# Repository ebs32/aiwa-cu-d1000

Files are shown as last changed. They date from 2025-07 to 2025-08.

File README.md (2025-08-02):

# AIWA CU-D1000 HiFi

A repository where I track all the work I do for servicing my AIWA CU-D1000 HiFi System.

**Note** When opening schematics in OrCAD Capture, you may need to update the library paths, as Capture stores absolute paths for libraries, which can cause issues when the project is moved or cloned.

## MX-D10 Amplifier

### Audio Power Amplifier Replacement

Due to audio performance issues, I tested the amplifier by injecting a signal and monitoring the output. While increasing the volume, one of the channels failed. Upon further inspection, I found that the installed audio power amplifier IC, the **STK4204MK2**, is rated for a maximum supply voltage of **55 VDC**, whereas the measured rail voltage was approximately **56 VDC**, slightly exceeding the recommended limit.

It is likely that the unregulated power supply caused the rail voltage to rise from the nominal **51 VDC** (as specified in the service manual) to approximately **56 VDC** when the mains input increased from **220 VAC** to **230 VAC**, around 2003. However, this particular unit was not in use at that time. I also observed that increasing the volume causes the supply rail to step up from **25 VDC** to **51 VDC**.

With the original IC damaged, a replacement was necessary; however, sourcing one proved challenging, as most of these devices are only available through aftermarket channels. I identified a reseller claiming to offer a genuine **STK4204MK5**, a compatible model featuring lower total harmonic distortion (THD) and a higher maximum supply voltage rating of **57 VDC**.

Since I had to remove the heatsink to install the new IC, I took the opportunity to replace the old thermal paste with thermal pads to improve heat transfer from all regulators mounted to the heatsink, as well as from the new audio power amplifier IC.

### Audio Power Amplifier Filter Capacitor Replacement

When I opened the MX-D10 amplifier, I found that the filter capacitors for the audio power amplifier were swollen:

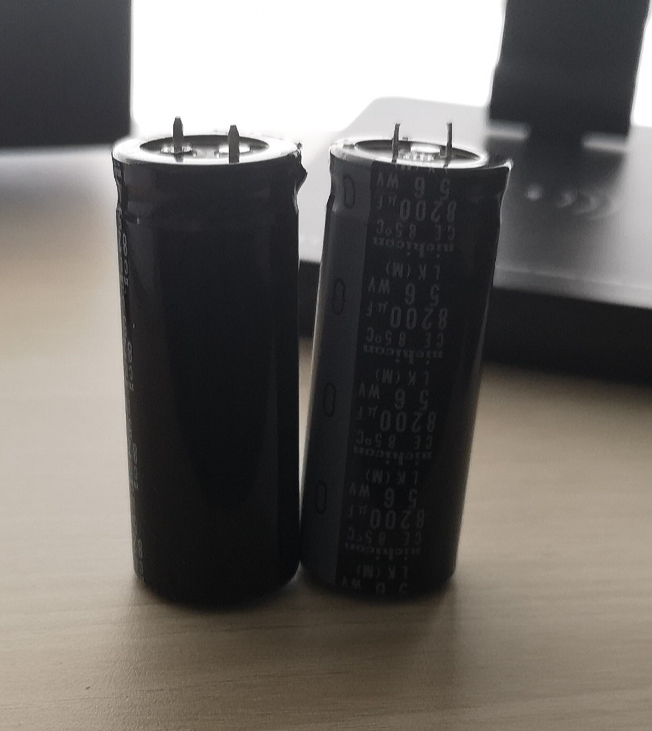
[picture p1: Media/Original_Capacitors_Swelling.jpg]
Original_Capacitors_Swelling


Since I could not find capacitors that fit in the available space on the main PCB, I had to come up with an alternative. Based on the options available from authorized resellers, I designed a simple PCB to mount the new capacitors:

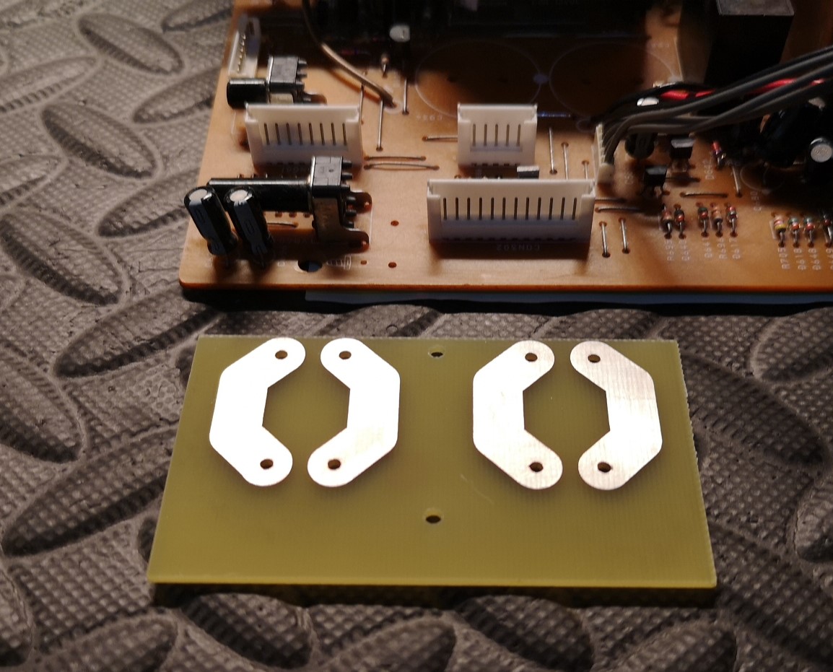
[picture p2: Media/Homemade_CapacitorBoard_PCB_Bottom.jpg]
Homemade_CapacitorBoard_PCB_Bottom


I also designed a mechanical support to mount the PCB. It attaches to the heatsink of the bridge rectifier, which is located behind the capacitors being replaced:

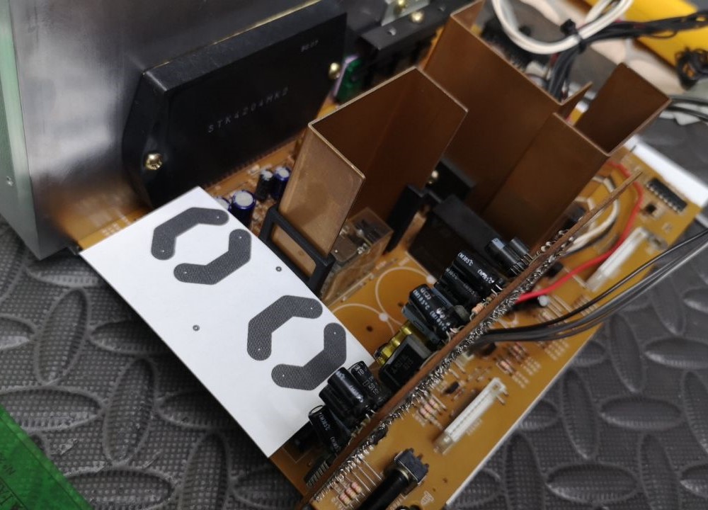
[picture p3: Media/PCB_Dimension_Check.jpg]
PCB_Dimension_Check


The PCB is connected to the main board using manually twisted wires:

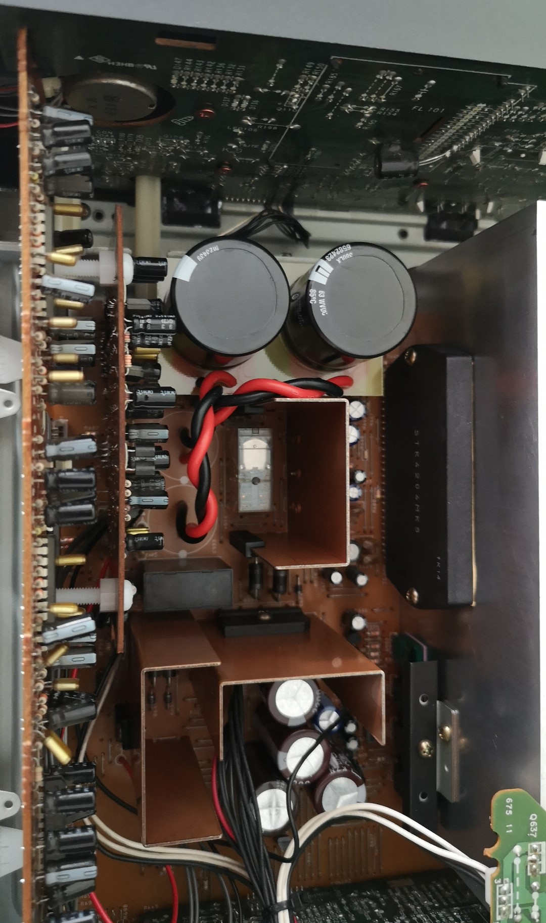
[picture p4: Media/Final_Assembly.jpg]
Final_Assembly


The PCB design is available in the [CapacitorBoard](Boards/CapacitorBoard/) directory, and the mechanical support design can be found in the [Designs](Designs/) directory.

### Filter Capacitor Replacement

Although the installed filter capacitors appeared to meet specifications, I opted to replace all of them.

## FX-W10 Cassette Deck

There was noticeable noise coming from the capstan motor of each deck, so I carefully disassembled them, cleaned all components, and lubricated the bearings. The noise is now nearly imperceptible.

## TX-D10 Tuner

The clock suffers from clock drift. I thought the ceramic crystal oscillator was the cause, so I replaced it. However, the drift still persists. I suppose I forgot those times when clocks needed periodic manual adjustments, so I’m not concerned about it.

## DX-D10 CD Player

I identified a couple of issues with the CD player.

One of them is read errors when playing slightly scratched discs. Although I purchased a CD optical pickup unit advertised as NOS (New Old Stock) to replace the existing one, I decided not to proceed, as the original unit still reads most discs without errors. Additionally, performance can be improved by fine-tuning the focus bias, tracking gain, and tracking balance.

The other issue was that the CD tray would close immediately after opening, preventing a disc from being placed on it. I fixed the issue by cleaning the switch that detects whether the tray is open or closed.

## References

The service manual for the amplifier, the cassette deck, the tuner and the graphic equalizer is available [here](Docs/CU-D1000_ServiceManual.pdf). I could not find the service manual for the CD player or the turntable.

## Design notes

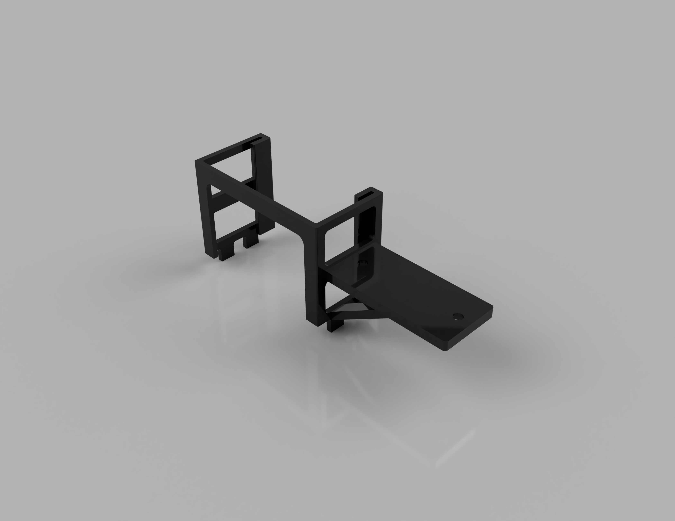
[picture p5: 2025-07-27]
Media/CapacitorBoard_Support_Render.png

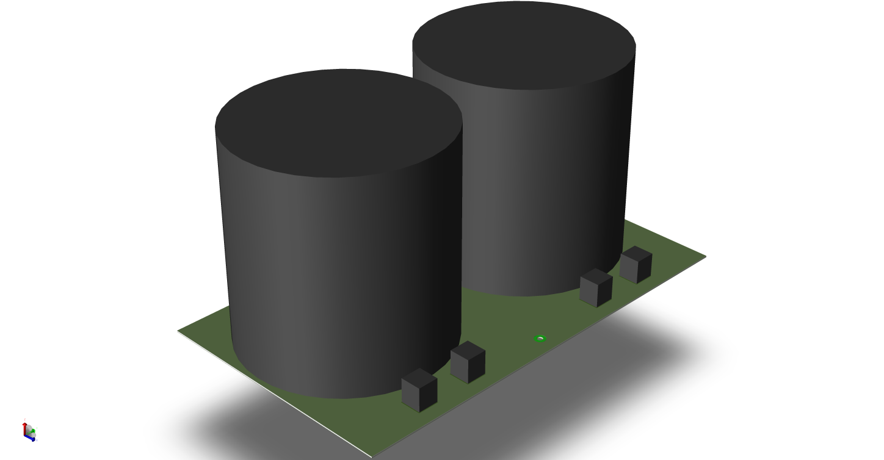
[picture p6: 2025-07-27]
Media/CapacitorBoard_3D_View_Top.png

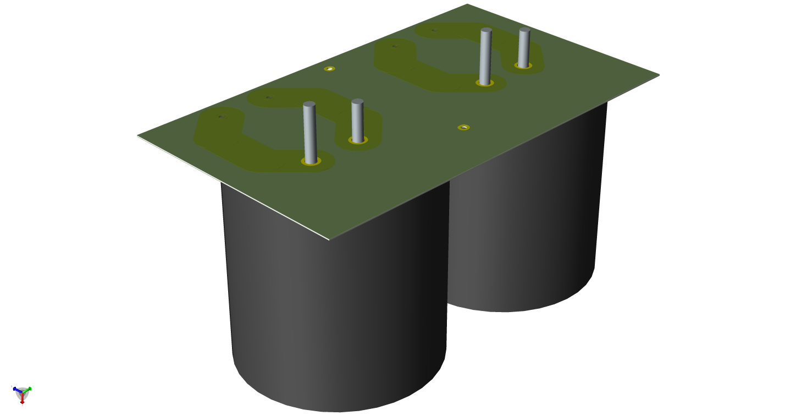
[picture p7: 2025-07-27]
Media/CapacitorBoard_3D_View_Bottom.png

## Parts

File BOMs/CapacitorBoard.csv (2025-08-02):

Reference | Part Number
C1 | 380LX822M063A032
C2 | 380LX822M063A032

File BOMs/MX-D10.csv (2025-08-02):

Reference | Part Number
C676 | ELXZ250ELL471MJ16S
C677 | EKZN250ELL682MMP1S
C678 | UPM1J102MHD6AA
C931 | EKY-350ELL332MMP1S
C932 | EKY-350ELL332MMP1S
MISC | PL-05-5-1016
MISC | 4051100100017

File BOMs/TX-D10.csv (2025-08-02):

Reference | Part Number
CR1 | CSTLS4M19G56-A0
CR1 | CSTLS4M19G53-A0

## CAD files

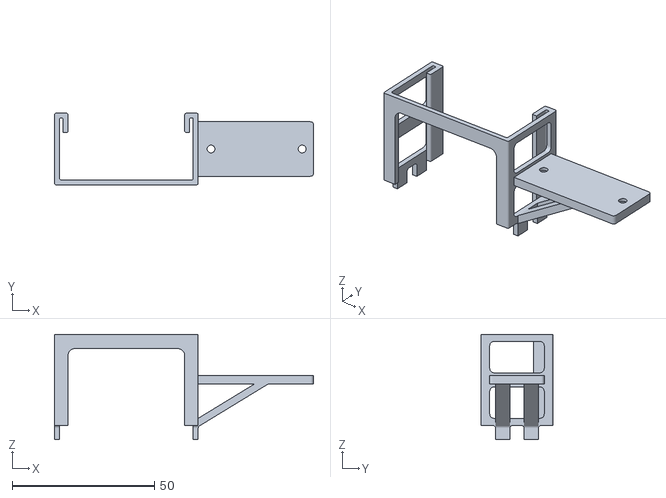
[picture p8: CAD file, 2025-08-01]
Manufacturing/Mechanical/CapacitorBoard_Support.stl
91.0 x 25.1 x 37.0

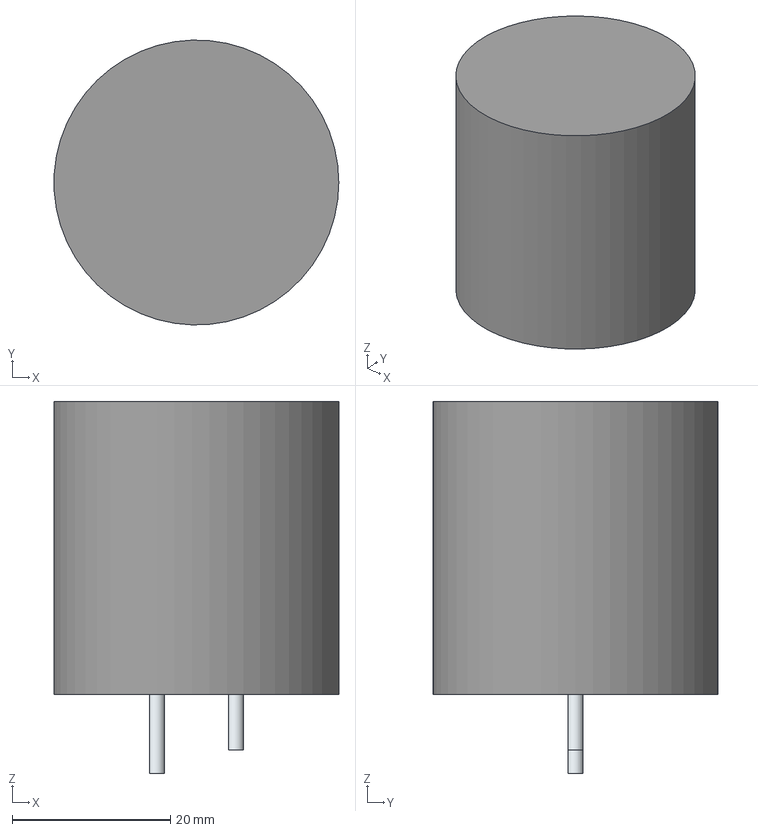
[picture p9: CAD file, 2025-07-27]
Boards/Symbols/380LX822M063A032.stp
36.0 x 36.0 x 47.0 mm
SimpleBody
Pin1
Pin2

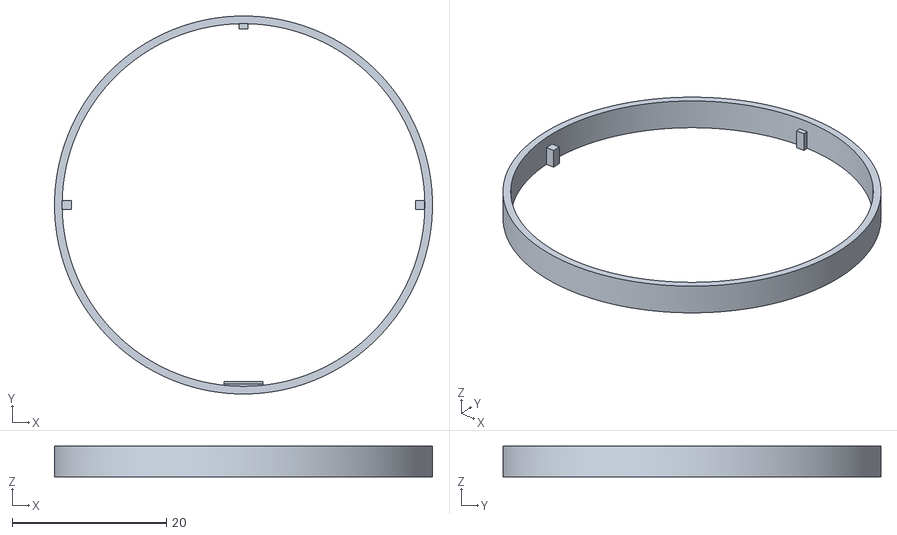
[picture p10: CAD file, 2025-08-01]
Manufacturing/Mechanical/Foot_Cover.stl
49.0 x 49.0 x 4.00

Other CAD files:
Boards/Symbols/009176001873906.psm
Boards/Symbols/CAPPRD1000W190D3550H3700.psm
Designs/CapacitorBoard_Support.f3z
Designs/Foot_Cover.f3d

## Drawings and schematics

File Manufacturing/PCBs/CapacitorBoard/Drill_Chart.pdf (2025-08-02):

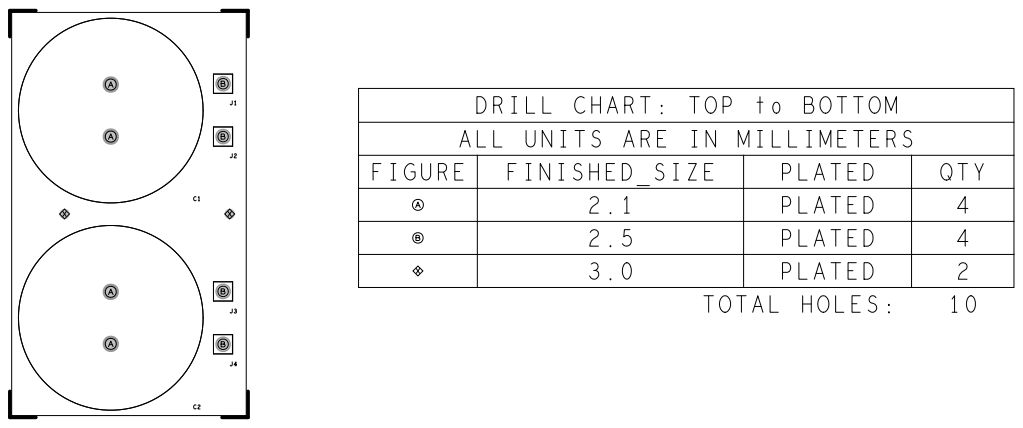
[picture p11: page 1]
FIGURE; DRILL CHART:; TOP to BOTTOM; TOTAL HOLES:; PLATED; QTY

ALL UNITS ARE IN MILLIMETERS
FINISHED_SIZE

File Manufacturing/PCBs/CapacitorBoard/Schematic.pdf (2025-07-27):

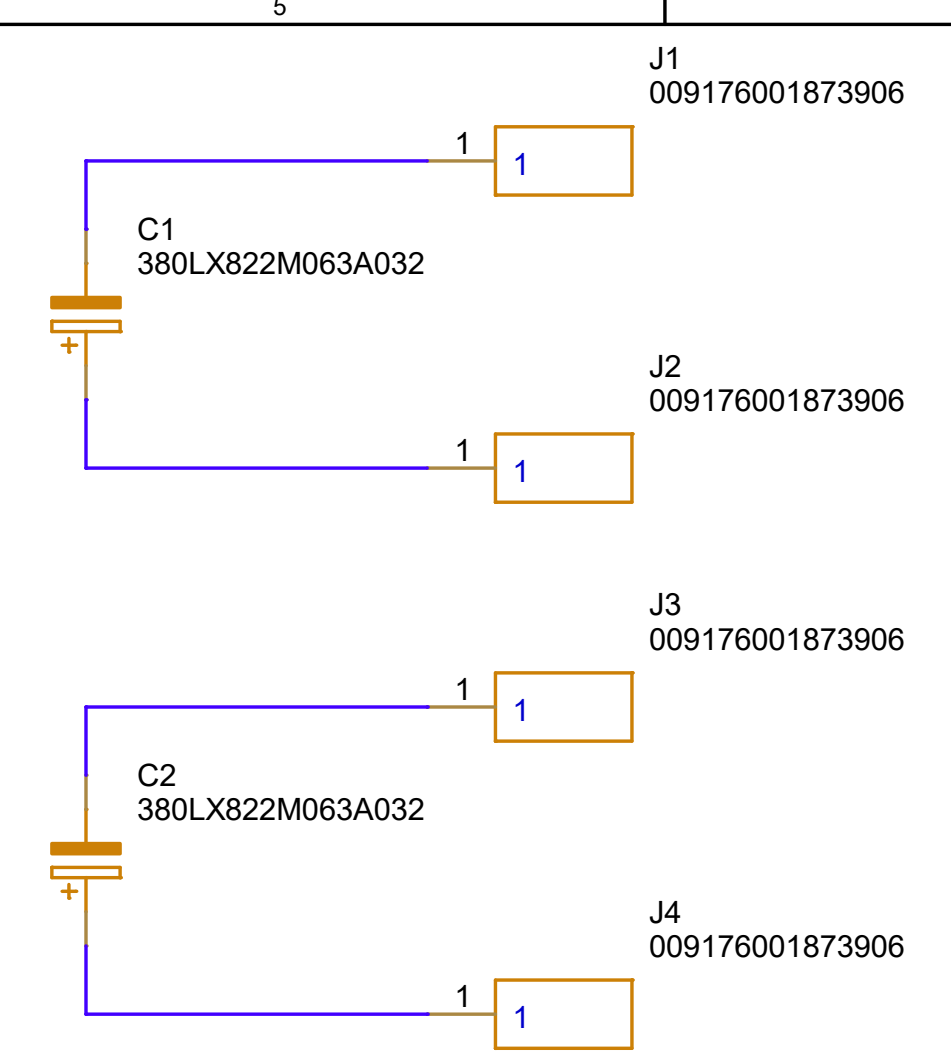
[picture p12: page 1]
Size; Document Number; Rev; Date:; Sheet; Capacitor Board; Saturday, July 26, 2025; Title

SBE Electronics / EBS
Title

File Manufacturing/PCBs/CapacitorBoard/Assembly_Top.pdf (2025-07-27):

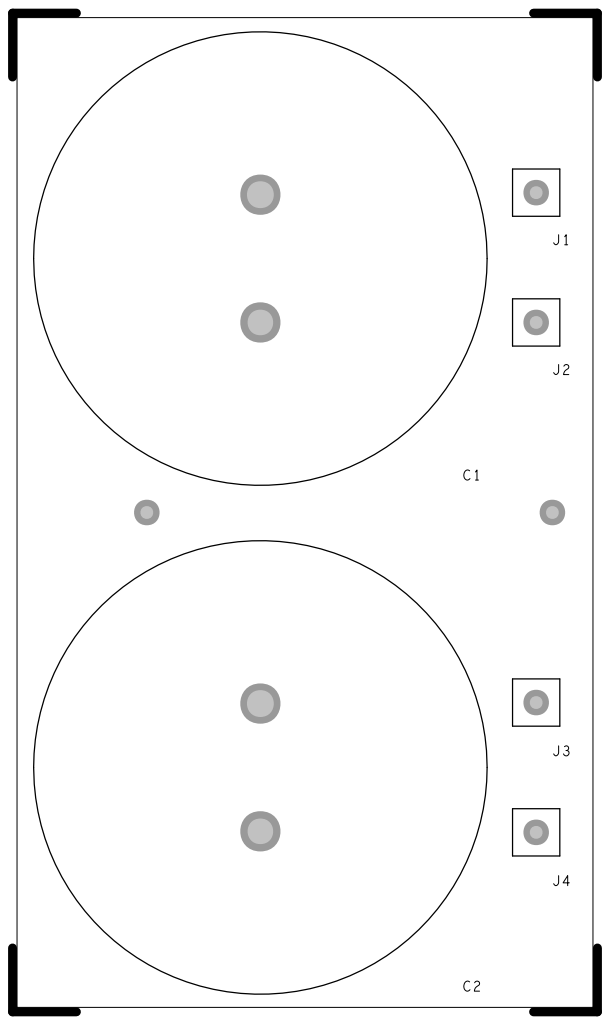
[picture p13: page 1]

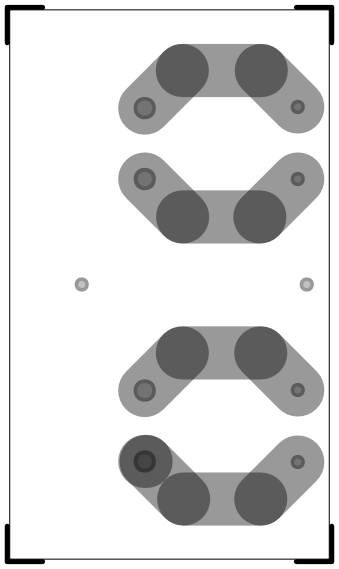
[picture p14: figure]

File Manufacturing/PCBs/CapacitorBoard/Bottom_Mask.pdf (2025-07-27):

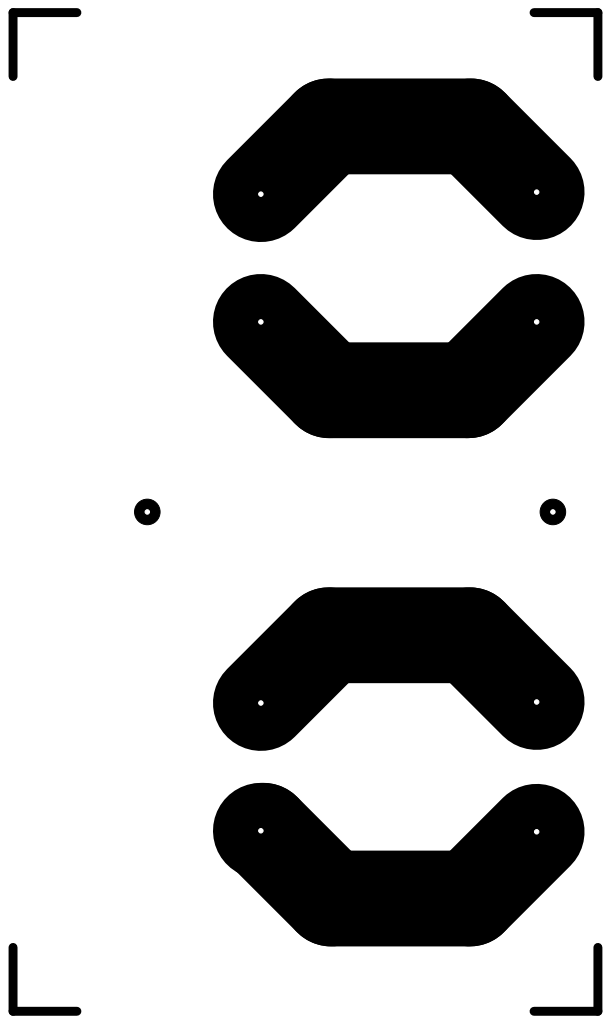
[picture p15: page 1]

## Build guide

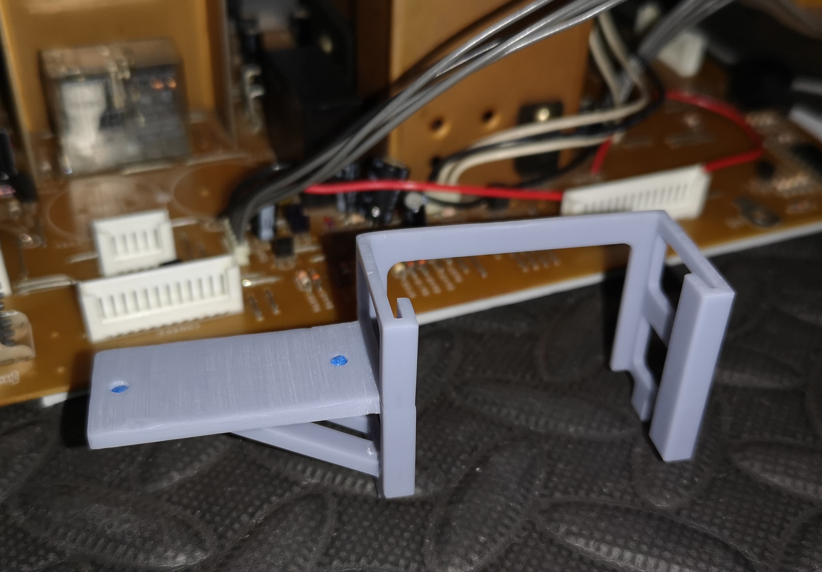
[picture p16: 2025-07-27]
Media/CapacitorBoard_Support_3D_Printed.jpg

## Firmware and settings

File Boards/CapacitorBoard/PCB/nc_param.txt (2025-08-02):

INTEGER-PLACES         2
DECIMAL-PLACES         5
X-OFFSET               0.000000
Y-OFFSET               0.000000
FEEDRATE               1
COORDINATES            ABSOLUTE
OUTPUT-UNITS           ENGLISH
TOOL-ORDER             INCREASING
REPEAT-CODES           NO
SUPPRESS-LEAD-ZEROES   NO
SUPPRESS-TRAIL-ZEROES  YES
SUPPRESS-EQUAL         NO
TOOL-SELECT            YES
OPTIMIZE_DRILLING      NO
ENHANCED_EXCELLON      YES
HEADER                 none
LEADER                 12
CODE                   ASCII
SEPARATE               NO
SEPARATE-ROUTING       NO
DRILLING               LAYER-PAIR
BACKDRILL              NO
COUNTER                NO
CAVITY                 NO
TOLERANCE_DRILL        NO
TOLERANCE_TRAVEL       NO
TOOL_SIZE              NO
ROTATION               NO
NON_STANDARD           NO
TOTAL_DRILL            YES
SEPARATE_SLOT          NO
SUPPRESS_TOLERANCE     NO
SUPPRESS_TOOLSIZE      NO
SUPPRESS_ROTATION      NO

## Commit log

2025-07-27 Added initial layout (#1)
    [009176001873906.psm, 009176001873906.stp, 380LX822M063A032.stp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]
2025-07-27 Fixed capacitor board PCB filename case (#2)
    [CapacitorBoard.brd, capacitorboard.brd]
2025-07-28 Updated README and renamed some files (#3)
    [CAPPRD1000W190D3550H3700.psm, CapacitorBoard.dsn, CapacitorBoard_Support.f3z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]
2025-07-30 Updated README and fixed minor issues (#4)
    [CapacitorBoard.dsn]
2025-08-01 Added Foot Cover and updated Capacitor Board STL (#5)
    [CapacitorBoard_Support.stl, Foot Cover.f3d, Foot Cover.stl]
2025-08-02 Added BOMs, Drill Chart, and Gerber ZIP (#6)
    [CapacitorBoard.brd, CapacitorBoard.csv, CapacitorBoard_Support.stl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]
